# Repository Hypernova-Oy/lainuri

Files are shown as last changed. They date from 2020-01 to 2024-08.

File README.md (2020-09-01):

# Lainuri - open hardware library self-checkout device

## Dual license

- GPL-3 for all software
- TAPR Open Hardware License for everything else

## Open Source is Love

Buy from us at [Hypernova](https://www.hypernova.fi/lainuri-self-checkout-machine/)

## Deploying a new Lainuri to your library

### Place an order

- Choose your colour and engravings from [Cotter](https://cotter.co/materials/)

### Preparations in your Koha instance

- Prepare a separate user in Koha for each Lainuri. The Lainuri vendor needs to know the:
  - branchcode
  - username
  - password
  - your Koha-instance's URL

  The Lainuri-user needs the following permissions:
    - circulate -> circulate_remaining_permissions
    - borrowers -> view_borrowers
    - auth -> get_session

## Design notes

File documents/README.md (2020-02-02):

Contains confidential and proprietary documents from device vendors.

make archive

make unarchive

To access the files with proper passphrase

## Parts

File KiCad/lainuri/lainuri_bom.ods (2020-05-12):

Reference | Value | Footprint | Datasheet | ALV0%€ | Model | Vendor | Manufacturer | Title | Length | Supplier | BodyHeight | Alternative model
BCR1 | Barcode_Reader |  |  | 44.78 | WGI3220USB | WinsonChina
RFID_RW1 | RFID_readerwriter |  |  | 56.65 | RL866 | Guangzhou Andea
AST1 | AST-1732MR-R | Koha-Suomi:AST-1732MR-R | https://www.mouser.fi/datasheet/2/334/AST-1732MR-R-72511.pdf | 3.5 | AST-1732MR-R |  | PUI Audio | Speakers & Transducers SPEAKER 32OHM
D1 | D | Koha-Suomi:1N4154TAP | https://www.mouser.fi/datasheet/2/427/1n4154-241332.pdf | 0.135 | 1N4154TAP |  | Vishay Semiconductors | Diodes - General Purpose, Power, Switching Vr/35v Io/150mA
D2 | D | Koha-Suomi:1N4154TAP | https://www.mouser.fi/datasheet/2/427/1n4154-241332.pdf | 0.135 | 1N4154TAP |  | Vishay Semiconductors | Diodes - General Purpose, Power, Switching Vr/35v Io/150mA
CAT1 | Cat-cable | Koha-Suomi:Bad_board_tag | ~ | 9.8 | 557-345 |  | RS PRO | RS Pro Red Cat6 Cable F/UTP LSZH, 5m | 5m | fi.rsdelivers.com
RPi1 | RPi_GPIO | Koha-Suomi:PI_GPIO_Header_F_2x20 |  | 2.27 |  |  | Adafruit | 40 Pin Extra Tall Header (Push Fit Version) |  | thepihut.com | 13.5mm
SW1 | SW_Push_LED | Connectors_Molex:Molex_KK-6410-04_04x2.54mm_Straight |  | 1.7 | ADA1439 | thepihut.com |  | 16mm Illuminated Pushbutton - Red Momentary
SOC1 | SoC | Koha-Suomi:Bad_board_tag | https://thepihut.com/products/raspberry-pi-4-model-b?variant=20064052740158 | 61.22 | Raspberry Pi 4 Model B |  | Raspberry Pi | Raspberry Pi 4 Model B |  | https://thepihut.com
SD1 | SD_Card | Koha-Suomi:Bad_board_tag |  | 12 | NOOBS_32GB_Retail |  | Raspberry Pi | SD Card preloaded with NOOBS - 32GB |  | fi.rsdelivers.com
RPE1 | RPi_Enclosure | Koha-Suomi:Bad_board_tag | https://thepihut.com/collections/featured-products/products/aluminium-armour-heatsink-case-for-raspberry-pi-4 | 13.6 | TPH-002 |  |  | Aluminium Armour - Heatsink Case for Raspberry Pi 4 |  | https://thepihut.com
US1 | USB-Stick |  |  | 17.2 | THN-U401S0320E4 |  | Toshiba | Toshiba 32GB TransMemory USB2.0 Metal |  | fi.rsdelivers.com
HDMI1 | Cable_HDMI-mini_to_HDMI (Raspi to touch screen) |  | https://thepihut.com/products/diy-usb-or-hdmi-cable-parts-10-cm-ribbon-cable | 1.7 | ADA3560 |  |  | DIY USB or HDMI Cable Parts - 10 cm Ribbon Cable | 0.1m | thepihut.com
N2 | External enclosure |  |  | 200 |  |  | cotter.co | Laser cut enclosure sheets that are glued together. Price varies based on customer needs.
T2 | Screw_Terminal_01x02 | Koha-Suomi:Screw_Terminal_01x02 (Molex) | https://www.mouser.fi/datasheet/2/276/0398800302_TERMINAL_BLOCKS-167600.pdf | 0.648 | 39880-0302 |  | Molex | Fixed Terminal Blocks 2 CKT TERM. BLOCK 5.08mm
EC2 | EC2-3TNU | Koha-Suomi:EC2-3TNU | https://www.mouser.fi/datasheet/2/212/KEM_R7002_EC2_EE2-1104574.pdf | 2.42 | EC2-3TNU |  | KEMET | Low Signal Relays - PCB 3V 2A Dbl Latching LL=3.2mm
TSCR1 | Touch_screen |  |  | 126.36 | GC1316 |  |  | 13.3 inch capacitive touch screen monitor 1920*1080 wit
UHUB1 | USB_Hub_4port |  | ~ | 10 |  | Shenzhen Lcr Industries |  | Ultra thin 4 Ports usb 3.0 Splitter Hub with DC Power Interface f
SC1 | Step_down_24V-12VA2 |  |  | 3.52 |  | Yucoo Network Equipment Co |  | Step down regulator 24v to 12v 3a step down dc dc converter
SC2 | Step_down_24V-5VA3.1 |  |  | 3.52 |  | Yucoo Network Equipment Co |  | Step down regulator 24v to 5v 3.1a step down dc dc converter
H1 | HEADER_S_1X02 |  | https://www.mouser.fi/datasheet/2/276/1/0687980010_CABLE_ASSEMBLIES-1315736.pdf | 6.78 | 68798-0010 | www.mouser.fi | Molex | Raspberry USB-C PSU Cable
THPR1 | Thermal_printer |  |  | 63.96 | HS-K33 | HSPOS TECHNOLOGY LIMITED
N3 | PCB mnfcture |  |  | 20 |  |  | allpcb.com | PCB printing and shipping (constant R&D no batch orders)
HDMI1.1 | DIY HDMI Head |  |  | 6.8 | ADA3549 | thepihut.com |  | DIY HDMI Cable Parts - Right Angle (R bend) HDMI Plug Adapter
HDMI1.2 | DIY HDMI Head |  |  | 6.8 | ADA3558 | thepihut.com |  | DIY HDMI Cable Parts - Left Angle (L Bend) Micro HDMI Plug |  |  |  | DIY HDMI Cable Parts - Straight Micro HDMI Plug Adapter (ADA3556)
RS_USB1 | RS-232-adapter |  |  | 15.87 | ADA18 | thepihut.com |  | USB/Serial Converter
HS2 | Heatsink |  | https://fi.rsdelivers.com/product/abl-components/bga-std-090/heatsink-10k-w-239-x-40-x-10mm-adhesive-foil/7500932 | 1.9 | BGA STD 090 | fi.rsdelivers.com | ABL Components
HS1 | Heatsink |  | https://fi.rsdelivers.com/product/abl-components/bga-std-090/heatsink-10k-w-239-x-40-x-10mm-adhesive-foil/7500932 | 1.9 | BGA STD 090 | fi.rsdelivers.com | ABL Components
 |  |  | YHTEENSÄ | 695.168
 |  |  | Pientarvikelisä | 25
 |  |  | Rahdit ja tullit | 150
 |  |  | YHTEENSÄ | 870.168

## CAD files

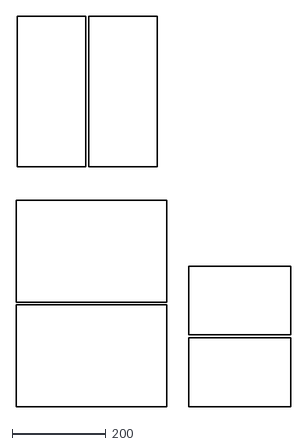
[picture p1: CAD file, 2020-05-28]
enclosures/Lainuri-press-cork-10mm.dxf
583.9 x 830.9

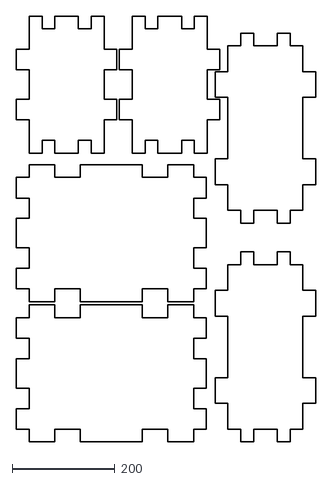
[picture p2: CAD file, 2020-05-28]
enclosures/Lainuri-press-plywood.dxf
583.9 x 830.9

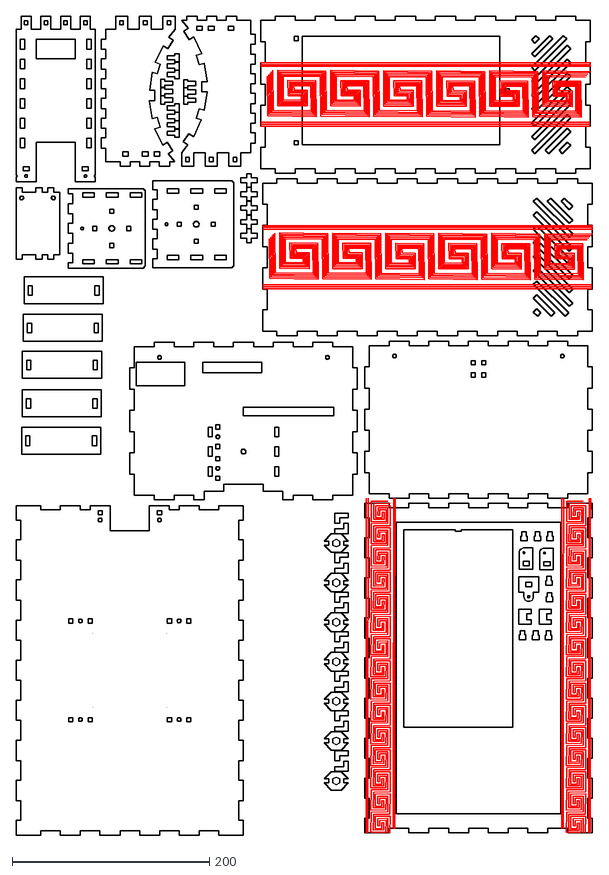
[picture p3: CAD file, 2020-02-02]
enclosures/Lainuri-enclosure-4.5mm.dxf
584.2 x 829.6

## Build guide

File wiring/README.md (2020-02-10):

# Wiring instructions

Piezo + -> BCM 18
Piezo - -> Physical 14
Push button + -> BCM 24
Push button - -> BCM 23

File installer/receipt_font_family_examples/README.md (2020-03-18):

# font-family examples for receipts

Here you can find the css3 'font-family'-directive's Lainuri-supported fonts that are available for use, and their example receipts outputs.

Put the font-family of the receipt to the

    'devices.thermal-printer.css.font-family' -configuration key

to enable the font for receipt printing.

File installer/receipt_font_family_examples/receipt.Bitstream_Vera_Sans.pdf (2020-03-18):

18.03.2020 font-family:Bitstream Vera Sans

Johda joelle
Juhannus, heilutin
"V" mustia joutsenia
Edessä toivolla hautaan
Koko punaisen syyskuun ajan Taivaalla palo-päällystetty Pyysin sinua esiintymään
Kuin piikki pyhille

Külm oli mu hing
Sõnatu oli valu
Ma seisin silmitsi, kui mu maha jätsid Roos vihmas
Nii et ma vandusin su habemenuga See pole kunagi lummatud
Kas teie tumedad küüned usku
Mind surutakse uuesti läbi mu veenide

Bared on your tomb
I am a prayer for your loneliness
And would you ever soon
Come above unto me?
For once upon a time
From the binds of your lowliness
I could always find
The right slot for your sacred key

Шесть футов глубиной является разрез В моем сердце эта безбрачная тюрьма Обесцвечивает все с туннельным зрением Sunsetter
Nymphetamine
Больной и слабый от моего состояния Эта похоть, вампирская зависимость Ей одной в полном подчинении
Не лучше
Nymphetamine

苯丙胺，苯丙胺
苯丙胺女孩
苯丙胺，苯丙胺
我的安非他命女孩

مطحم كرحسب
انأ طاحم ةرئادب لثم ةسيرفلا ةدوعلا يف ةباغلا
ثيح تاسمه عنقت
ديزملا نم تاراسم ركسلا
تعضو رثكأ ةديس ءاضيب
نم ناكرأ حلملا
ظفح مودس يل ال يف جيلخ

Paisg gu mo ghàirdeanan
Cùm an slighe mesmeric aca
Agus dannsa a-mach chun na gealaich Mar a rinn sinn anns na làithean òrail sin

Estrellas de bautizo
Recuerdo el camino
Éramos aguja y cuchara
Extraviados en el heno ardiente

Útilokað í gröfinni þinni
Ég er bæn fyrir einmanaleika þínum Og myndir þú alltaf fljótlega
Komið hér til mín?
Í eitt skipti fyrir
Frá bindindum heilagleika þinna Ég gat alltaf fundið
Réttur rifa fyrir þinn heilaga lykil

Seks meter dypt er snittet
I mitt hjerte, det barløse fengselet Misfarger alt med tunnelsyn Suns
Nymphetamine
Syk og svak fra tilstanden min
Denne lysten, en vampyravhengighet Til henne alene i full underkastelse Ingen bedre
Nymphetamine

Մայրամուտ
Նիմֆետամին
Ոչինչ ավելի լավ
Նիմֆետամին

Νυμφεταμίνη, νυμφεταμίνη
Νυμφεταμίνη κορίτσι
Νυμφεταμίνη, νυμφεταμίνη
Η νυμφεταμίνη μου

font-family:Bitstream Vera Sans

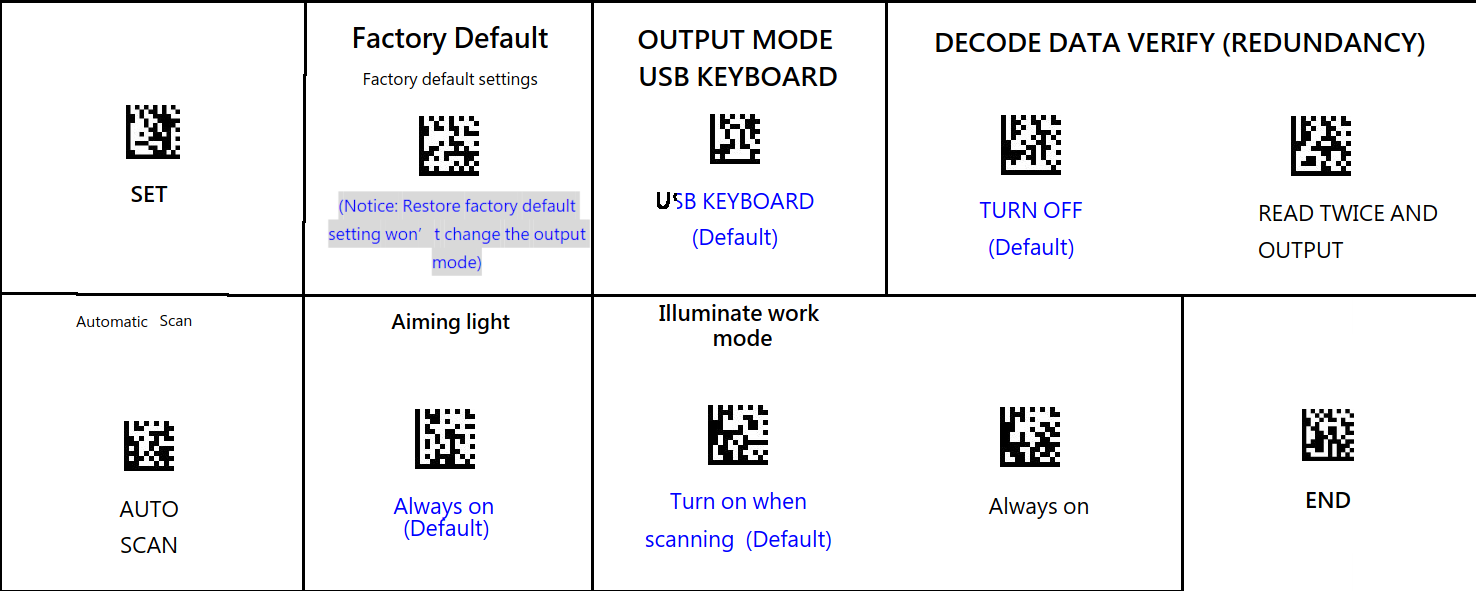
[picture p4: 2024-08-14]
installer/barcode_reader/WGI3220USB/USB_HID.png

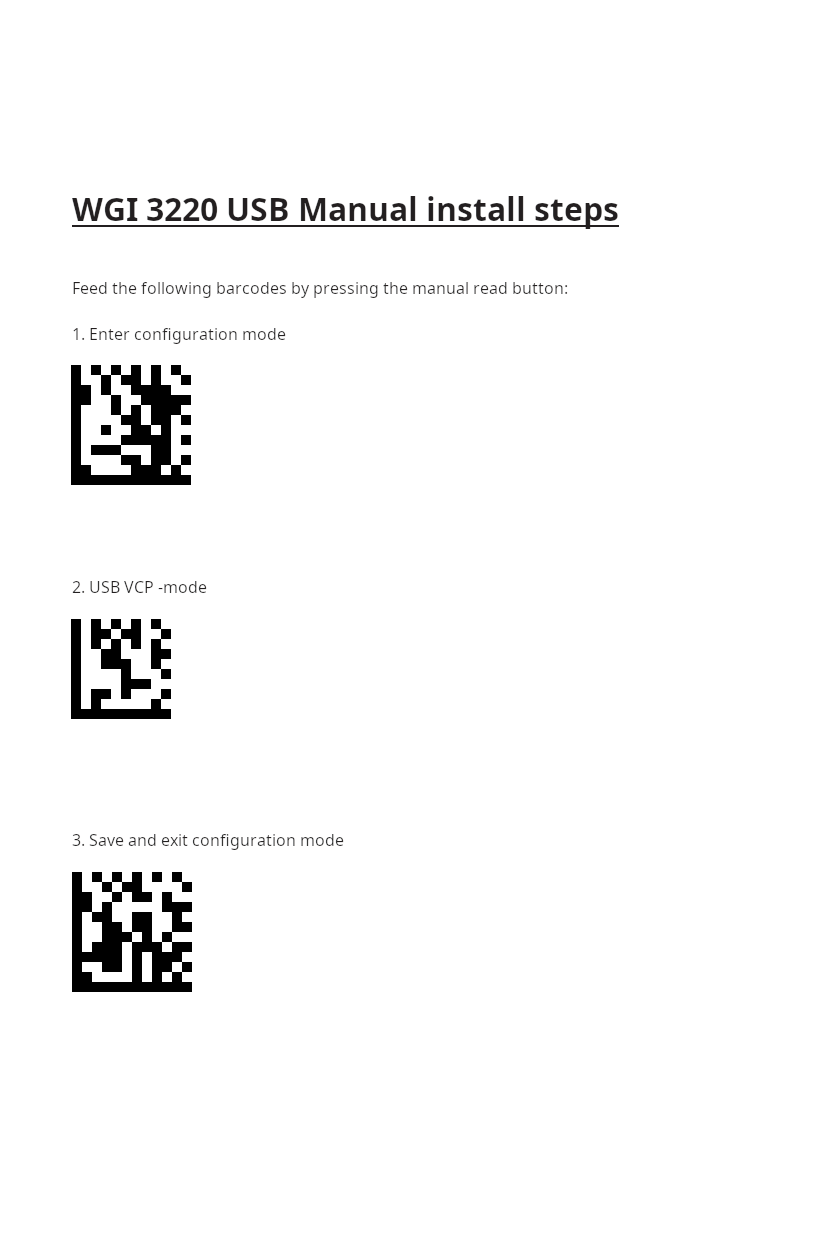
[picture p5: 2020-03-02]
installer/barcode_reader/WGI3220USB/Manual_install_steps.png

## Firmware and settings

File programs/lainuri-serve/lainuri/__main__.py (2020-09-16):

from lainuri.config import get_config
from lainuri.logging_context import logging
log = logging.getLogger(__name__)

from pprint import pprint
import time

def handle_signal_SIGUSR1(signum, frame):
  import lainuri.event_queue
  print(f"Received signal SIGUSR1 '{signum}' '{frame}'")
  start = lainuri.event_queue.hii - 10 if lainuri.event_queue.hii - 10 > 0 else 0
  pprint([e.__dict__ for e in lainuri.event_queue.history[start:start+10] if e != None])


if __name__ == '__main__':
  import signal
  log.info("Binding signal handlers, SIGUSR1")
  signal.signal(signal.SIGUSR1, handle_signal_SIGUSR1)

  import lainuri.websocket_server
  try:
    lainuri.websocket_server.start(ws_daemon=False)
  finally:
    lainuri.websocket_server.stop()

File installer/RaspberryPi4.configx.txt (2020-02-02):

Raspberry Pi 4 configurations

Append to:

/etc/xdg/lxsession/LXDE-pi/autostart

this:

# ANSIBLE-MANAGED
# As the display is rotated, force the touch screen to rotate with the screen
# see:
#   xinput --list
# for the device name
DISPLAY=:0 xinput --set-prop 'ILITEK ILITEK-TP' 'Coordinate Transformation Matrix' 0 1 0 -1 0 1 0 0 1
# EOF ANSIBLE-MANAGED




sudo apt install xinput-calibrator
sudo apt-get install matchbox-keyboard





PSU:
AC->DC Alibaba

https://www.mouser.fi/ProductDetail/CUI/PYBE20-Q24-S5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

USB-C DIY charger cable. GND+5V

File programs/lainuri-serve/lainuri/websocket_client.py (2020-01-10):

from lainuri.config import get_config
from lainuri.logging_context import logging
log = logging.getLogger(__name__)

from websocket import WebSocket, WebSocketApp
import websocket

try:
  import thread
except ImportError:
  import _thread as thread
import time
import json


def test_run(ws: WebSocket, string: str =''):
  ws.send(json.dumps({
    'event': 'ringtone-play',
    'ringtone_type': 'success',
  }))
  ws.send(json.dumps({
    'event': 'ringtone-play',
    'ringtone': 'ToveriAccessGranted:d=4,o=5,b=100:32c5,32b4,32c5,4d5',
  }))
  ws.send(json.dumps({
    'event': 'config-getpublic',
  }))


def on_message(ws: WebSocket, message):
  print(message)

def on_error(ws: WebSocket, error):
  print(error)

def on_close(ws: WebSocket):
  print("### closed ###")

def on_open(ws: WebSocket):
  thread.start_new_thread(test_run, (ws,''))


if __name__ == "__main__":
    websocket.enableTrace(True)
    ws = WebSocketApp(
      "ws://localhost:53153/",
      on_message = on_message,
      on_error = on_error,
      on_close = on_close
    )
    ws.on_open = on_open
    ws.run_forever()

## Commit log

2020-01-10 Test event to mock device rfid and barcode reads.
2020-01-10 Check device enablement earlier
2020-01-18 Refactored barcode to item_barcode and user_barcode where applicable. Bugfixes to RFID.
    [event.py, rfid_reader.py, websocket_server.py]
2020-01-19 Thermal printer backend integration works without front-end browser printing!
2020-01-19 Receipt printing via UI
2020-01-25 Thermal printer work, Barcode reader models support.
2020-01-26 Work continues across the board.
2020-02-02 Refactored to Trunk-based project structure.
    [Lainuri-RFID-pad-3mm.2.dxf, Lainuri-RFID-pad-3mm.dxf, Lainuri-enclosure-3mm.dxf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]
2020-02-02 Fix thermal printer jinja2 default template.
    [printer.py]
2020-02-03 UI Overlay notifications for Koha messages and statuses. Refactoring messages to request/response instead of separate failed-state.
    [event.py]
2020-02-10 Enclosure + Wiring diagram - Fix assembly issues. Printer internal mounting improvements. RFID enclosure improvements.
    [Lainuri-RFID-pad-3mm.2.dxf, Lainuri-RFID-pad-3mm.dxf, Lainuri-enclosure-3mm.dxf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]
2020-02-12 Enclosure - More assembly fixes. One-piece nut holder is now mainstream. Top plate cannot be misassembled now.
    [Lainuri-export-3mm.dxf]
2020-02-12 Enclosure - Move Raspberry so the cat-cable can be changed. Thermal printer adjustments.
    [Lainuri-export-3mm.dxf]
2020-02-12 Enclosure - Wiring improvements. Thermal printer paper roll improvements.
    [Lainuri-export-3mm.dxf]
2020-02-15 Ansible installer. Thermal printer installer fixes.
2020-02-15 Barcode reader configured to work reliably in low-loght conditions. + prod fixes.
    [WGI3220USB.py, WGI_commands.py, barcode_reader.py]
2020-02-15 WIP - Thermal printer detect paper status and has it been torn away.
2020-02-16 Lainuri-UI - Render device status icons and tooltips.
2020-03-02 Fixing tests and loading tag information via ISO 15693
    [WGC300UsbAT.py, WGI3220USB.py, event.py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]
2020-03-04 Test suite towards event_queue driven. Fixing complete test suite run issues.
    [event_queue.py, rfid_reader.py, websocket_server.py]
2020-03-09 Server - Myriad fixes. Better exception handling. Refactoring.
    [config.py, event.py, event_queue.py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]
2020-03-09 UI - checkin refactored. Transaction stages management in the UI.
2020-03-11 BarcodeReader - polling thread can survive Exceptions.
2020-03-17 Lainuri-UI/serve - Added locale to the receipt printing.
2020-03-18 Lainuri-UI - locale receipt printing fixes.
    [printer.py]
2020-03-19 Lainuri-UI/serve - Schema validation for config. Backend locale support + set from UI. Fixed all tests.
    [config.py, event.py, helpers.py]
2020-04-09 Lainuri-serve - Fix check-in receipt template path.
    [printer.py]
2020-04-30 Lainuri-serve - WIP RL866 interrupt inventory instead of polling.
    There is a probable hardware problem that it might not be possible to implement this via ISO15693
2020-05-02 lainuri-serve - Allow disabling 'devices.rfid-reader.double-check-gate-security'
    This speeds up check-in/out by 300-500ms
2020-05-03 lainuri-serve - Thermal printing overhaul. Configurable print heat/speed/precision, CUPS replaced with ESC/POS.
    A bit more faster.
    Enable getting printer status codes, such as paper out.
    [escposser.py, helpers.py, hs_k33.py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]
2020-05-05 lainuri-serve - udev-rules to map devices to lainuri:lainuri with friendly symlinks
2020-05-05 lainuri-serve - Thermal printer thread safety and receipt tear off detection
2020-05-05 lainuri-serve - Thermal printer test_page()
2020-05-12 KiCad - Electronic schematic and parts.
    [lainuri.kicad_pcb, lainuri.sch, lainuri_bom.ods]
2020-05-12 lainuri-serve - Threading and event logging improvements. Trim the LEvent from excess attributes.
2020-05-12 lainuri-serve - Introduce Threadbase to manage lifecycle of all threads.
2020-05-12 lainuri-ui/serve - HTTP connection issues Exception showing on UI. Logging improvements etc.
    [event.py, websocket_server.py]
2020-05-13 lainuri-serve - Better exception handling. Try to pinpoint strange RFID gate security bug.
    [rfid_reader.py]
2020-05-28 lainuri-serve - Real-time status change event notifications. Improving device statuses detection.
2020-05-28 Enclosure - Adjustable table stand. Enclosure assembly press.
    [Lainuri-export-3mm.dxf, Lainuri-press-cork-10mm.dxf, Lainuri-press-plywood.dxf]
2020-06-01 lainuri-serve - PrintJob transaction object. LEPrintTestRequest/Response returning the rendered image.
2020-06-10 lainuri-ui - TemplateEditor WIP
    + json-parse-better-errors dependency
    [event.py, printer.py]
2020-08-10 lainuri-serve - HS-K33 bugfixes
    [hs_k33.py]
2020-08-20 lainuri-ui - Hide cursor always
    Better for touch devices, so the cursor is not let at the position of last touch
2020-08-20 lainuri-ui - Hide "close and print" option when nothing has been checked-out/in
2020-08-22 lainuri-serve - hs_k33.py bug in websocket response error handler
    [printer.py]
2020-08-27 lainuri-serve - Fix ItemCard status switch initial double touch to toggle status.
    Needed to touch the ItemCard twice initially to toggle the status.
    This was wrong.
    Only one touch is needed to toggle status.
2020-08-27 lainuri-ui - TemplateEditor bigger font, more horizontal space. Button texts.
2020-08-28 enclosure - Sub-millimeter adjustments for better fitting of thermal printer paper and enclosure to base plate
    [Lainuri-export-3mm.dxf]
2020-08-28 enclosure - Many new improvements.
    Improved enclosure reinforcements.
    Better positioning for push button and piezo.
    Reduced excessive material from internal mount PSU holder.
    USB hub mount point in base plate.
    Stand cover plates 0.1mm wider to physically loc in place.
    Stand mounting sablon to drill holes.
    Guide sticker to maintenance hatch to remind which way paper roll is put in place.
    [Lainuri-export-3mm.dxf]
2020-09-03 lainuri-serve - HS-K33 - Trying to debug failing "Print raster bit image" -commands. Need support from the vendor regarding device return codes.
    [hs_k33.py, printer.py, websocket_server.py]
2020-09-03 lainuri-serve - server status program version is set on boot, to avoid unnecessary extra status messages to clients
    [status.py]
2020-09-03 lainuri-serve - HS-K33 - Trying to debug failing "Print raster bit image" -commands. Followup 1.
    [hs_k33.py]
2020-09-03 lainuri-serve/ui - disabling the thermal printer removes the "print receipt"-option from the UI
2020-09-03 lainuri-serve - HS-K33 - Trying to debug failing "Print raster bit image" -commands. Followup 2.
    [hs_k33.py]
2020-09-03 lainuri-ui - OverlayNotification configurable timeout to close the popup. timeout_poller refactored to support parallel timers/intervals.
2020-09-04 lainuri-serve - HS-K33 - Fix USB Overflow error where the USB responses are sporadic.
    [hs_k33.py]
2020-09-04 lainuri-ui - Checkout/In - Make action buttons bigger
2020-09-07 lainuri-serve - HS-K33 - Trying to debug failing "Print raster bit image" -commands. Followup 3.
    Try encapsulating the receipt printing into a complete transaction.
    Adjust timings a bit to prevent sending escpos commands to the device while it is printing.
    [hs_k33.py]
2020-09-07 lainuri-ui - CheckIn/Out - Hide "print receipt" if overlay notifications active.
2020-09-08 lainuri-serve/ui - Show RFID inventory errors to the user, so he could stop wiggling those damn books around.
    [event.py, rfid_reader.py]
2020-09-09 lainuri-serve/ui - Show RFID inventory errors to the user. Specific RFIDInventory-exception used.
    [rfid_reader.py]
2020-09-11 lainuri-serve - rtttl-player now uses the emb-rtttl system daemon via unix domain socket. Exposed rpc endpoint for play_rtttl()
2020-09-16 lainuri-serve - rtttl-player - Fix exception description bug
    [rtttl_player.py]
2020-09-18 lainuri-serve - HS-K33 fix printer crashing on rather big receipts
    [hs_k33.py]
2020-09-28 lainuri-serve - WGI-3220 Error detection increased to READ THRICE
    [WGI3220USB.py, WGI_commands.py]
2020-09-29 lainuri-serve - Only one logging format with millisecond precision
2020-10-01 lainuri-serve/ui - Propagate exception_ils.PermissionMissing to the GUI to better understand which permissions are missing.
    [event.py, websocket_server.py]
2021-03-14 KiCad - Remove *.sch-bak temp backups from git
2021-03-14 FreeCAD - Enclosure improvements. New barcode reader mounts. Clean excess pieces.
